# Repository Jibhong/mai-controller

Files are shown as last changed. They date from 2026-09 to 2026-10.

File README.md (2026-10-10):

# My washing machine game
I made this circular game controller at home without any power tools and keeping the cost as low as possible so the design might look very different from other peoples build.

## The problems
> Cost and space are my first concerns, so instead of using 42inch tv i use two 27 inch monitor + 1 laptop monitor for sub display this way i can easily get 120fps or even higher for fraction of a price of 43inch tv because for most small tv the 120hz varient only sony bravo lcd and lg c oled both are more premium models at around 22k thb but mine can go as low as 7,000 thb as of today (included monitor arm) and can be use as normal desktop monitor saving spaces a lot.
> Another concerns is that I don't power tools so all of my materials are pre-cut and i can build this only with a few screws and a soldering iron.

Note: **Currently I have finished only 80% of the project that is touch sensors but it is 99% playable at this stage.**

<details open>
<summary><b>Table of Contents</b></summary>
  
- [Header](#my-washing-machine-game)
- [Price summary](#price-summary)
- [Bill of Materials](#bill-of-materials)
  
</details>

# Price summary
The controller itself cost less than 6,000 thb not including the screens.
For monitor on the top I have Asus VG279 and the bottom one is Lenovo 27U-10.
You can use your old monitor or if buying new one you can fine entry level 27inch 144hz monitor for as low as 2,800thb and a monitor arm.

# Bill of Materials

## Touch Screen

| Qty | Item | Notes |
|---|---|---|
| 4 | OTA coated A4 PET film one side no glue | < 40 ohm/square. Mine are cut slightly short on the short side, the pdf file have compensates on both axes |
| 20 | OCA glue 7.9in | check dimensions first it must fit largest A pad. 7.9in is for tablet-sized not phone |
| 1 | Pi Pico 2 | |
| 3 | MPR121 breakout board | |
| 1 | Breadboard and wires | or solder directly to the Pico (only a few wires) |
| 2m | 4-core wire | |
| 1 | Double-sided conductive copper tape | |
| 1 | 0.1 mm copper wire | or strip any stranded wire |
| 1 | Clear tape | |
| 1 | Hot glue | or use OCA / clear tape |
| 1 | 5 mm tempered glass, 560x560 mm | |
| - | 2 mm EVA foam | for padding the glass |
| 1 | 3D printer + 400g PETG | |

## Frame (2020 Aluminium)

| Qty | Length |
|---|---|
| 2 | 550 mm |
| 2 | 565 mm |
| 2 | 600 mm |
| 5 | 760 mm |
| 2 | 900 mm |

| Qty | Item | Notes |
|---|---|---|
| 14 | Angle bracket | |
| 38 | Shelf support for 2020 | you actually need only 4 on each corner and risk it break |
| - | Screws and fasteners | |

## Buttons

Buy one or 3d print.

| Qty | Item | Notes |
|---|---|---|
| 3m | 9 core wire | I use 10 core |
| 8 | Mechanical keyboard switch | |
| 8 | Rod R=5mm L=80mm | |
| 1 | 3D printer + 2kg PETG | |

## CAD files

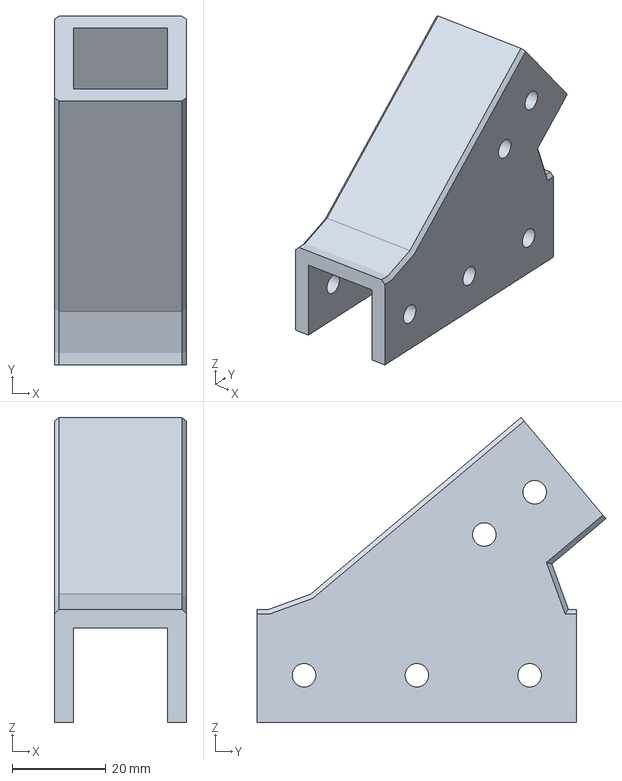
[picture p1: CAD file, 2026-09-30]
CAD/top-40-bracket.3mf
28.1 x 74.2 x 64.9 mm

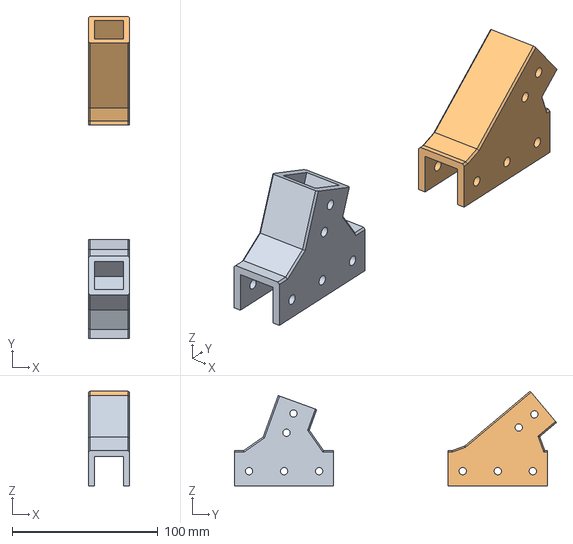
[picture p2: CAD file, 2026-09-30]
CAD/bracket.FCStd
28.1 x 220.7 x 64.9 mm
bottom-70-bracket
top-40-bracket

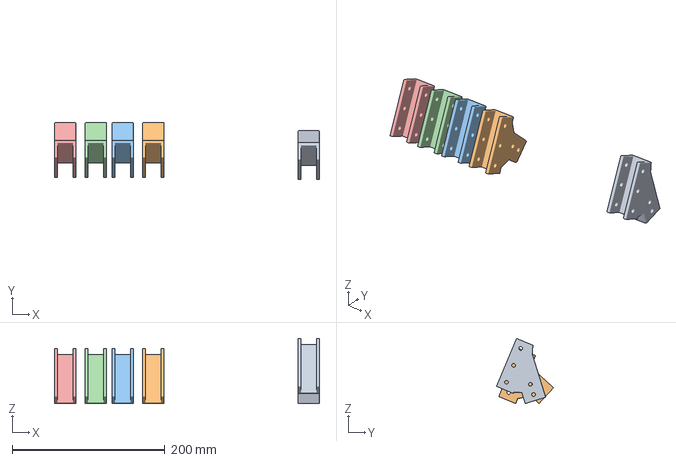
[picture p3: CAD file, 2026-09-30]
CAD/3dprint.3mf
346.6 x 74.7 x 85.2 mm

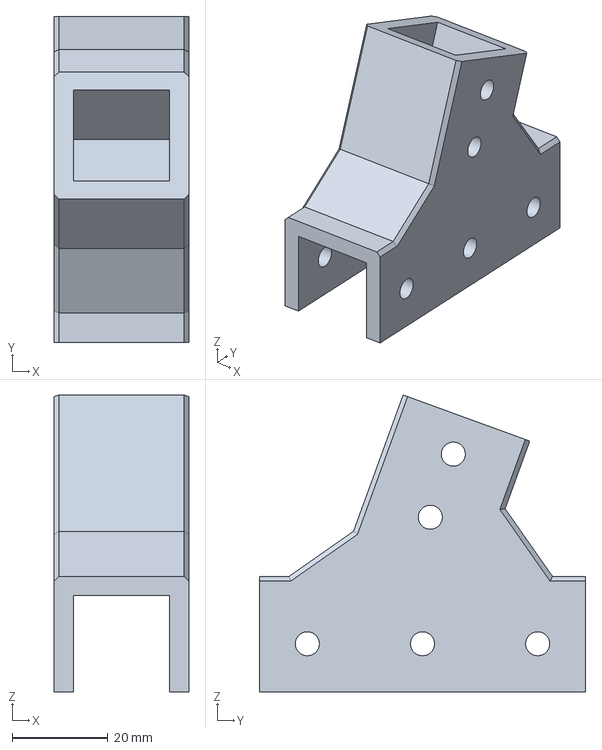
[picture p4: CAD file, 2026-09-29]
CAD/bottom-70-bracket.3mf
28.1 x 68.0 x 61.9 mm

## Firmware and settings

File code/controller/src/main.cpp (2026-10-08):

#include <Arduino.h>
#include <USB.h>
#include <Wire.h>

extern "C" {
#include "mpr121.h"
}

// =============================================================================
//  MPR121 I2C Addresses
//  chip 0 = 0x5A, 1 = 0x5B, 2 = 0x5C
// =============================================================================
static constexpr uint8_t MPR121_ADDR[3] = {0x5A, 0x5B, 0x5C};

// How many MPR121 chips are actually connected and initialized.
// Must match the loop limit in setup().
#define NUM_MPR121  3

// =============================================================================
//  Action encoding
//
//  Each MPR121 pin maps to one of:
//    UNUSED          - ignored
//    TOUCH(row, col) - mai2 touch zone, using ROW_x constants below
//    BTN(n)          - game button 0-7 (bit n in game_btn byte)
//
//  Encoding in int16_t:
//    >= 0  -> flat touch zone index (see ROW_x offsets)
//    -1    -> UNUSED
//    < -1  -> game button: value = -(btn_index + 2)
//
//  mai2 touch zone flat index layout (34 zones total, 5 per byte):
//    A1-A8 = 0..7
//    B1-B8 = 8..15
//    C1-C2 = 16..17   (C only has 2 zones)
//    D1-D8 = 18..25
//    E1-E8 = 26..33
// =============================================================================
#define UNUSED       ((int16_t)(-1))
#define TOUCH(row_base, col) ((int16_t)((row_base) + (col) - 1))
#define BTN(n)       ((int16_t)(-((n) + 2)))

// Row base offsets into the 34-zone flat array
#define ROW_A  0
#define ROW_B  8
#define ROW_C  16   // C1=16, C2=17 only
#define ROW_D  18
#define ROW_E  26

// =============================================================================
//  *** EDIT THIS TABLE TO CONFIGURE YOUR WIRING ***
//
//  mpr_map[chip][pin]   chip = 0..2,  pin = 0..11
//
//  Example entries:
//    TOUCH(ROW_A, 1)  ->  touch zone A1
//    TOUCH(ROW_E, 8)  ->  touch zone E8
//    BTN(0)           ->  game button 1  (0x01 in mai2 game-btn word)
//    BTN(7)           ->  game button 8  (0x80)
//    UNUSED           ->  not connected
// =============================================================================
static const int16_t mpr_map[3][12] = {
    // --- MPR121 chip 0 (addr 0x5A) ---
    //  pin 0            pin 1            pin 2            pin 3
    //  pin 4            pin 5            pin 6            pin 7
    //  pin 8            pin 9            pin10            pin11
    {
        TOUCH(ROW_A, 2), TOUCH(ROW_C, 1), TOUCH(ROW_B, 2), TOUCH(ROW_D, 2),
        TOUCH(ROW_E, 2), TOUCH(ROW_A, 1), TOUCH(ROW_B, 1), TOUCH(ROW_D, 1),
        TOUCH(ROW_E, 1), TOUCH(ROW_A, 8), TOUCH(ROW_B, 8), UNUSED,
    },

    // --- MPR121 chip 1 (addr 0x5B) ---
    {
        TOUCH(ROW_A, 5), TOUCH(ROW_B, 5), TOUCH(ROW_D, 5), TOUCH(ROW_E, 5),
        TOUCH(ROW_A, 4), TOUCH(ROW_B, 4), TOUCH(ROW_D, 4), TOUCH(ROW_E, 4),
        TOUCH(ROW_A, 3), TOUCH(ROW_B, 3), TOUCH(ROW_D, 3), TOUCH(ROW_E, 3),
    },

    // --- MPR121 chip 2 (addr 0x5C) ---
    {
        TOUCH(ROW_D, 8), TOUCH(ROW_E, 8), TOUCH(ROW_A, 7), TOUCH(ROW_B, 7),
        TOUCH(ROW_D, 7), TOUCH(ROW_E, 7), TOUCH(ROW_C, 2), TOUCH(ROW_A, 6),
        TOUCH(ROW_B, 6), TOUCH(ROW_D, 6), TOUCH(ROW_E, 6), UNUSED,
    },
};

// =============================================================================
//  Packet layout (16 bytes total):
//
//   [0]      SYNC0  = 0xAA
//   [1]      SYNC1  = 0x55
//   [2]      seq    (rolling counter)
//   [3..9]   touch_state[7]  - mai2 A1-E8 bitfield (5 zones per byte, low 5 bits)
//   [10]     game_btn        - bits 0-7 = game buttons 1-8 (active-high)
//   [11]     air_packed      - bits 0-5 = air beams 0-5
//   [12]     test_btn
//   [13]     service_btn
//   [14]     coin_btn
//   [15]     checksum (XOR of bytes [2]..[14])
// =============================================================================
static constexpr uint8_t SYNC0 = 0xAA;
static constexpr uint8_t SYNC1 = 0x55;
static constexpr size_t  PACKET_SIZE = 16;

static uint8_t seq_counter = 0;

// Sensor state
static uint8_t touch_state[7] = {0}; // mai2 A1-E8 bitfield
static uint8_t game_btn       = 0;   // bits 0-7 -> BTN1-BTN8
static uint8_t air_beams[6]   = {0};
static uint8_t test_btn       = 0;
static uint8_t service_btn    = 0;
static uint8_t coin_btn       = 0;

//

#define COL_GREEN "\033[42;30m"  // green background, black text
#define COL_RED   "\033[41;37m"  // red background, white text
#define COL_RESET "\033[0m"

void debug_mpr121(int mode) {
    static const uint8_t addrs[3] = {0x5A, 0x5B, 0x5C};

    for (int chip = 0; chip < 3; chip++) {
        uint8_t addr = addrs[chip];

        // Raw data: output pin_value_1 format (e.g. 756_1)
        if (mode & (1 << 0)) {
            uint16_t raw[12] = {0};
            uint16_t touched = mpr121_touched(addr);
            mpr121_raw(addr, raw, 12);

            for (int pin = 0; pin < 12; pin++) {
                uint8_t status = (touched >> pin) & 1;
                Serial.printf("%s%d_%d%s ",
                              status ? COL_GREEN : COL_RED,
                              raw[pin], status,
                              COL_RESET);
            }
        }
        // Touch state only if raw is not requested
        else if (mode & (1 << 1)) {
            uint16_t touched = mpr121_touched(addr);
            for (int pin = 0; pin < 12; pin++) {
                uint8_t status = (touched >> pin) & 1;
                Serial.printf("%s%d_%d%s ",
                              status ? COL_GREEN : COL_RED,
                              pin, status,
                              COL_RESET);
            }
            Serial.printf("| ");
        }
    }
    Serial.print("\n");
}


// =============================================================================
//  Helpers: set one touch bit or one game-button bit
// =============================================================================

// zone_index: 0=A1, 1=A2 ... 7=A8, 8=B1 ... 33=E2  (34 zones total)
// Packed 5 zones per byte: byteIdx = zone/5, bitIdx = zone%5
static inline void set_touch_bit(uint8_t zone) {
    if (zone >= 35) return;
    touch_state[zone / 5] |= (uint8_t)(1u << (zone % 5));
}

// btn_index 0-7 -> bit 0-7 of game_btn
static inline void set_game_btn_bit(uint8_t btn_index) {
    if (btn_index >= 8) return;
    game_btn |= (uint8_t)(1u << btn_index);
}

// =============================================================================
//  scan_slider() - iterate all 3 MPR121s, apply the lookup table
// =============================================================================
static void scan_slider() {
    memset(touch_state, 0, sizeof(touch_state));
    game_btn = 0;

    for (uint8_t chip = 0; chip < NUM_MPR121; chip++) {
        uint16_t touched = mpr121_touched(MPR121_ADDR[chip]);

        for (uint8_t pin = 0; pin < 12; pin++) {
            if (!((touched >> pin) & 1u)) continue;

            int16_t action = mpr_map[chip][pin];
            if (action == UNUSED) continue;

            if (action >= 0) {
                set_touch_bit((uint8_t)action);
            } else {
                // Decode game button index: action = -(idx+2) => idx = -(action+2)
                uint8_t btn_idx = (uint8_t)(-(action + 2));
                set_game_btn_bit(btn_idx);
            }
        }
    }
}

// =============================================================================
//  Air sensor scan (non-blocking, one sensor per loop iteration)
// =============================================================================
static void scan_air() {
    static uint32_t last_air_time  = 0;
    static bool     air_is_on      = false;
    static uint8_t  current_sensor = 0;

    if (!air_is_on) {
        digitalWrite(current_sensor, HIGH);
        last_air_time = micros();
        air_is_on = true;
        return;
    }
    if (micros() - last_air_time < 1000) return;

    // LOW = receiver sees IR (not blocked); HIGH = blocked
    air_beams[current_sensor] = (digitalRead(6 + current_sensor) == LOW) ? 1 : 0;

    digitalWrite(current_sensor, LOW);
    air_is_on = false;
    if (++current_sensor > 5) current_sensor = 0;
}

// =============================================================================
//  Op-button scan (physical pins, active-low with pull-up)
// =============================================================================
static void scan_buttons() {
    test_btn    = (digitalRead(13) == LOW) ? 1 : 0;
    service_btn = (digitalRead(14) == LOW) ? 1 : 0;
    coin_btn    = (digitalRead(15) == LOW) ? 1 : 0;
}

// =============================================================================
//  Hold pin 16 LOW to re-init all MPR121 chips (recovery without full reboot)
// =============================================================================
static void scanReboot() {
    static bool isInit = false;
    if (!isInit) { pinMode(16, INPUT_PULLUP); isInit = true; }
    if (digitalRead(16) == LOW) {
        delay(20);
        if (digitalRead(16) == LOW) {
            for (uint8_t chip = 0; chip < 3; chip++)
                mpr121_init(MPR121_ADDR[chip]);
        }
    }
}

// =============================================================================
//  Build and send one packet
// =============================================================================
static void send_packet() {

    uint8_t pkt[PACKET_SIZE];
    size_t i = 0;

    pkt[i++] = SYNC0;
    pkt[i++] = SYNC1;
    pkt[i++] = seq_counter++;

    // Touch state (7 bytes: A1-E8 in mai2io format)
    memcpy(&pkt[i], touch_state, 7); i += 7;

    // Game buttons (bits 0-7 = BTN1-BTN8)
    pkt[i++] = game_btn;

    // Air beams packed into 1 byte (bits 0-5)
    uint8_t air_packed = 0;
    for (uint8_t b = 0; b < 6; b++) air_packed |= (air_beams[b] & 1u) << b;
    pkt[i++] = air_packed;

    // Op buttons
    pkt[i++] = test_btn;
    pkt[i++] = service_btn;
    pkt[i++] = coin_btn;

    // Checksum: XOR of bytes [2..14]
    uint8_t checksum = 0;
    for (size_t j = 2; j < i; j++) checksum ^= pkt[j];
    pkt[i++] = checksum;

    Serial.write(pkt, PACKET_SIZE);
}

// =============================================================================
//  setup()
// =============================================================================
void setup() {
    // Custom VID/PID so the PC serial link code can reliably find us
    USB.disconnect();
    USB.setVIDPID(0x2E8A, 0x000A);
    USB.setManufacturer("Jibhong");
    USB.setProduct("MaiController");
    USB.connect();

    Serial.begin(115200);

    pinMode(LED_BUILTIN, OUTPUT);
    pinMode(16, INPUT_PULLUP);

    // Air TX (IR emitter) pins
    for (int p = 0; p <= 5; p++) {
        pinMode(p, OUTPUT);
        digitalWrite(p, LOW);
    }
    // Air RX (IR receiver) pins
    for (int p = 6; p <= 11; p++) {
        pinMode(p, INPUT_PULLUP);
    }

    // Op-button pins
    pinMode(13, INPUT_PULLUP);
    pinMode(14, INPUT_PULLUP);
    pinMode(15, INPUT_PULLUP);

    // I2C bus
    Wire1.setSDA(26);
    Wire1.setSCL(27);
    Wire1.begin();

    // Initialize all 3 MPR121 chips
    for (uint8_t chip = 0; chip < 3; chip++) {
        if (!mpr121_init(MPR121_ADDR[chip])) {
            Serial.print("MPR121 chip ");
            Serial.print(chip);
            Serial.print(" (0x5");
            Serial.print(0xA + chip, HEX);
            Serial.println(") not found - halting. Hold pin16 to reboot.");
            while (true) {
                digitalWrite(LED_BUILTIN, !digitalRead(LED_BUILTIN));
                delay(20);
                if (digitalRead(16) == LOW) {
                    delay(20);
                    if (digitalRead(16) == LOW) rp2040.reboot();
                }
            }
        }
    }
}

// =============================================================================
//  loop()
// =============================================================================
void loop() {
    scan_slider();
    scan_air();
    scan_buttons();

    send_packet();    
    // debug_mpr121((1<<0) | (1<<1));
    // debug_mpr121((1<<1));

    // Board LED mirrors any active input
    bool any_active = (game_btn != 0) || test_btn || service_btn || coin_btn;
    for (uint8_t b = 0; b < 7 && !any_active; b++)
        if (touch_state[b]) any_active = true;

    digitalWrite(LED_BUILTIN, any_active ? HIGH : LOW);

    scanReboot();

    delay(1);
}

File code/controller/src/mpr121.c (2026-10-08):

/*
 * MP121 Captive Touch Sensor
 * WHowe <github.com/whowechina>
 *
 */

#include <stdint.h>
#include <string.h>

#include "hardware/i2c.h"

#define I2C_PORT i2c1
#include "mpr121.h"

/* ========================= I2C ========================= */
#define IO_TIMEOUT_US          1000   // per-transfer I2C timeout (us)

/* ================== TOUCH / RELEASE THRESHOLDS ==================
 * Compared against (baseline - filtered data), in raw counts.
 * Lower = more sensitive and faster trigger, but more noise-prone.
 * Release must stay below touch (hysteresis) or it will chatter.
 * Per-electrode trim is applied in mpr121_sense().
 */
#define TOUCH_THRESHOLD_BASE   25   // counts of change to register touch (1-255)
#define RELEASE_THRESHOLD_BASE 20     // counts to register release (1-255), < touch

/* ============== DEBOUNCE (reg 0x5B) ==============
 * Number of consecutive scan cycles a state must hold before it is reported.
 * 0 = instant (lowest latency). Max 7. Each step adds one full scan cycle.
 */
#define DEBOUNCE_TOUCH         0      // cycles before reporting touch (0-7)
#define DEBOUNCE_RELEASE       0      // cycles before reporting release (0-7)

/* ============== SAMPLING / FILTER (regs 0x5C, 0x5D) ==============
 * FFI: first filter iterations (samples averaged per scan, in AFE reg)
 *      0 = 6, 1 = 10, 2 = 18, 3 = 34.   Lower = faster, noisier.
 * SFI: second filter iterations (number of scan results averaged)
 *      0 = 4, 1 = 6, 2 = 10, 3 = 18.    Lower = faster, noisier.
 * ESI: electrode sample interval (period between scans)
 *      0 = 1ms, 1 = 2ms, 2 = 4ms ... 7 = 128ms.  0 = fastest response.
 */
#define FILTER_FFI             1      // 0..3
#define FILTER_SFI             1      // 0..3
#define FILTER_ESI             0      // 0..7

/* ============== CHARGE (MANUAL MODE, autoconfig off) ==============
 * Signal level is proportional to CDC x CDT.
 * Raw reading all 1023 -> too much charge, lower CDC or CDT.
 * Baseline under ~200 -> too little charge, raise them.
 * Target: untouched baseline ~400-700, touch delta >= 30 counts.
 * Prefer short CDT + higher CDC for faster scanning.
 *
 * CDC = charge current in uA, 0-63 (per electrode).
 * CDT codes: 1=0.5us 2=1us 3=2us 4=4us 5=8us 6=16us 7=32us
 */
#define MANUAL_CDC             15     // charge current, 0-63 uA
#define MANUAL_CDT             3      // charge time code, 1-7
#define GLOBAL_CDC             0      // global CDC in AFE reg (unused when per-electrode set)

/* ============== AUTOCONFIG (alternative to manual charge) ==============
 * 1 = chip picks CDC/CDT per electrode at startup (ignores MANUAL_CDC/CDT).
 * 0 = use manual values above.
 */
#define USE_AUTOCONFIG         0

#define VDD                    3.3f
#define AC_HEADROOM            0.5f   // datasheet says 0.7; lower avoids autoconfig failure on big pads
#define AC_USL_F               1.00f  // upper limit scale (of VDD - headroom)
#define AC_LSL_F               0.55f  // lower limit (fraction of USL)
#define AC_TARGET_F            0.80f  // target baseline (fraction of USL), higher = bigger delta
#define AC_RETRY               2      // retries on fail: 0=off 1=2x 2=4x 3=8x
#define AC_BVA                 2      // baseline value adjust after autoconfig (0-3)
#define AC_ARE                 1      // auto-reconfig on out-of-range
#define AC_ACE                 1      // auto-config enable

/* ============== BASELINE FILTER (auto-recovery / drift tracking) ==============
 * The baseline is a slow-moving reference the chip subtracts from the signal.
 * Each direction has up to 4 parameters:
 *   MHD  max half delta    (1-63)  max step the baseline moves per update; bigger = faster tracking
 *   NHD  noise half delta  (1-63)  step size used for small changes; bigger = faster tracking
 *   NCL  noise count limit (0-255) consecutive samples needed before the baseline moves; lower = faster
 *   FDL  filter delay count(0-255) extra delay between baseline updates; lower = faster
 * Fast values = quick recovery from drift or stuck state, but a held touch
 * gets absorbed into the baseline and "releases" by itself.
 * Slow values = held touches stay valid, but recovery from drift is slow.
 */
// RISING: signal above baseline (e.g. after release, baseline re-converges up)
#define BL_RISE_MHD            1
#define BL_RISE_NHD            1
#define BL_RISE_NCL            4
#define BL_RISE_FDL            2

// FALLING: signal below baseline (touch direction, keep slower if you want holds)
#define BL_FALL_MHD            1
#define BL_FALL_NHD            1
#define BL_FALL_NCL            64
#define BL_FALL_FDL            64

// TOUCHED: baseline behavior while an electrode is touched (no MHD register)
#define BL_TOUCH_NHD           1
#define BL_TOUCH_NCL           4
#define BL_TOUCH_FDL           8

/* ============== ELECTRODE CONFIG (reg 0x5E) ==============
 * ECR_CL: baseline tracking / initial load
 *   0 = tracking on, start from existing baseline
 *   1 = tracking off
 *   2 = tracking on, init baseline from first reading (5 MSBs)
 *   3 = tracking on, init baseline from first reading (full 10 bits)
 * ELECTRODE_COUNT: electrodes scanned (1-12). Fewer = faster scan cycle.
 */
#define ECR_CL                 2
#define ELECTRODE_COUNT        12

#define INIT_RETRIES           5      // retries until out-of-range flags clear
#define INIT_SETTLE_MS         50     // wait after enabling electrodes

/* ========================= REGISTERS ========================= */
#define MPR121_TOUCH_STATUS_REG 0x00
#define MPR121_OUT_OF_RANGE_STATUS_0_REG 0x02
#define MPR121_OUT_OF_RANGE_STATUS_1_REG 0x03
#define MPR121_ELECTRODE_FILTERED_DATA_REG 0x04
#define MPR121_BASELINE_VALUE_REG 0x1E

#define MPR121_MAX_HALF_DELTA_RISING_REG 0x2B
#define MPR121_NOISE_HALF_DELTA_RISING_REG 0x2C
#define MPR121_NOISE_COUNT_LIMIT_RISING_REG 0x2D
#define MPR121_FILTER_DELAY_COUNT_RISING_REG 0x2E
#define MPR121_MAX_HALF_DELTA_FALLING_REG 0x2F
#define MPR121_NOISE_HALF_DELTA_FALLING_REG 0x30
#define MPR121_NOISE_COUNT_LIMIT_FALLING_REG 0x31
#define MPR121_FILTER_DELAY_COUNT_FALLING_REG 0x32
#define MPR121_NOISE_HALF_DELTA_TOUCHED_REG 0x33
#define MPR121_NOISE_COUNT_LIMIT_TOUCHED_REG 0x34
#define MPR121_FILTER_DELAY_COUNT_TOUCHED_REG 0x35

#define MPR121_TOUCH_THRESHOLD_REG 0x41
#define MPR121_RELEASE_THRESHOLD_REG 0x42
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

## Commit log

2026-09-23 70 deg aluminium bracket
    [bottom-70-bracket.3mf, bottom-70-bracket.FCStd]
2026-09-29 update 70 bracket added serial_link
    [3dprint.3mf, bottom-70-bracket.3mf, bottom-70-bracket.FCStd]
2026-09-30 added top 40 degree bracket
    [3dprint.3mf, bottom-70-bracket.FCStd, bracket.FCStd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]
2026-10-08 debug print color adjust sensitivity
2026-10-11 Clarify descriptions in materials list
    Updated item descriptions for clarity in the materials list.
2026-10-11 Update README with assembly and wiring instructions
    Added assembly instructions and wiring details for the project.
